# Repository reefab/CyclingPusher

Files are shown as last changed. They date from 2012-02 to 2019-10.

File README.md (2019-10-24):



# CyclingPusher

## Description

This project provides an [Arduino](http://arduino.cc/) sketch that can power an Arduino + Ethernet Shield (or Arduino with built-in ethernet) 
to make a stationary bike computer that can upload Cycling workout sessions results to [Runkeeper](http://runkeeper.com/)'s [Healthgraph API](http://developer.runkeeper.com/healthgraph).
This activity get added to the user's activities feed and could then be posted to Twitter or Facebook automatically by Runkeeper.

It doesn't need to be connected to a computer for that purpose, only a wired ethernet connection is required.

It'll also display the current speed and either the total distance or average speed or elapsed time during normal use via a LCD.

The sensor used is the [reed switch](http://en.wikipedia.org/wiki/Reed_switch) that was already present in my stationary bike connected to the Arduino with a pulldown resistor.

The elapsed time only counts 15 seconds chunks when there was some activity, otherwise it'll pause automatically.

If the pause last more than 2 minutes, it'll upload to Runkeeper the:

 * Starting Time
 * Total Distance
 * Elapsed Time

for the current session. From this, Runkeeper computes the average speed, pace and total calories burned.

## Usage

Plug the ethernet cable and the USB/Power cable in.
The Arduino will beep once it has obtained the current time and is ready for use.

Pedal away and it'll display the current speed while cycling between the total distance. average speed and elapsed time.

Stop pedaling for ~ 15 seconds and the pause screen will come up. 60 seconds, the lcd's backlight will be switched off. 2 minutes and it'll end the session and upload the result or discard the session if the "valid activity" threshold hasn't been reached.

It'll beep every 5km by default.

To start a new session, just use the bike again, it'll start over.

## In action

### Device
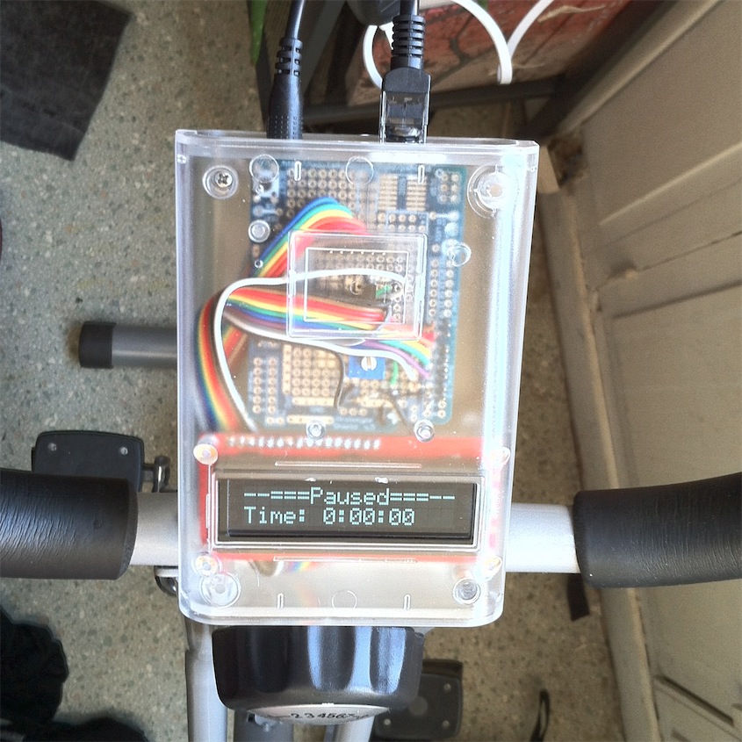
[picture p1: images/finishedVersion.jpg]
Device in clear enclosure

[Prototype during testing](https://github.com/reefab/CyclingPusher/raw/master/images/prototype.jpg)
[Stationary bike's reed switch and magnetic brake](https://github.com/reefab/CyclingPusher/raw/master/images/bike.jpg)
### Runkeeper screenshot
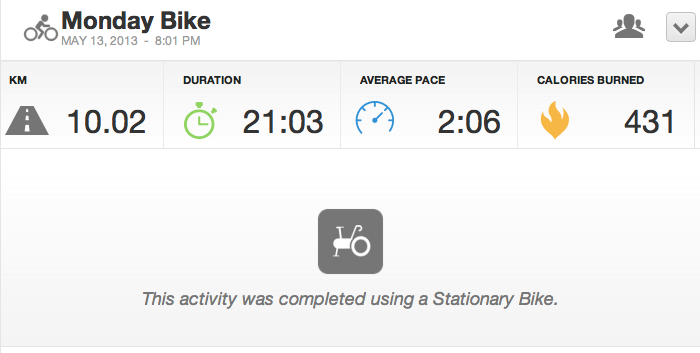
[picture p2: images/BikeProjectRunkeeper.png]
Runkeeper screenshot


## Setup

You'll need:

 * Runkeeper user account
 * create a Runkeeper app to get an access token (See below)
 * Arduino Uno + Ethernet shield or equivalent
 * 16x2 LCD
 * Stationary bike with a reed switch

The reed switch needs to be plugged in Pin2 to use the Arduino's hardware interrupts.

### Schematics

The [Fritzing](http://fritzing.org/) Schema file is available in the `Schematics` directory.
Here is the breadboard view:

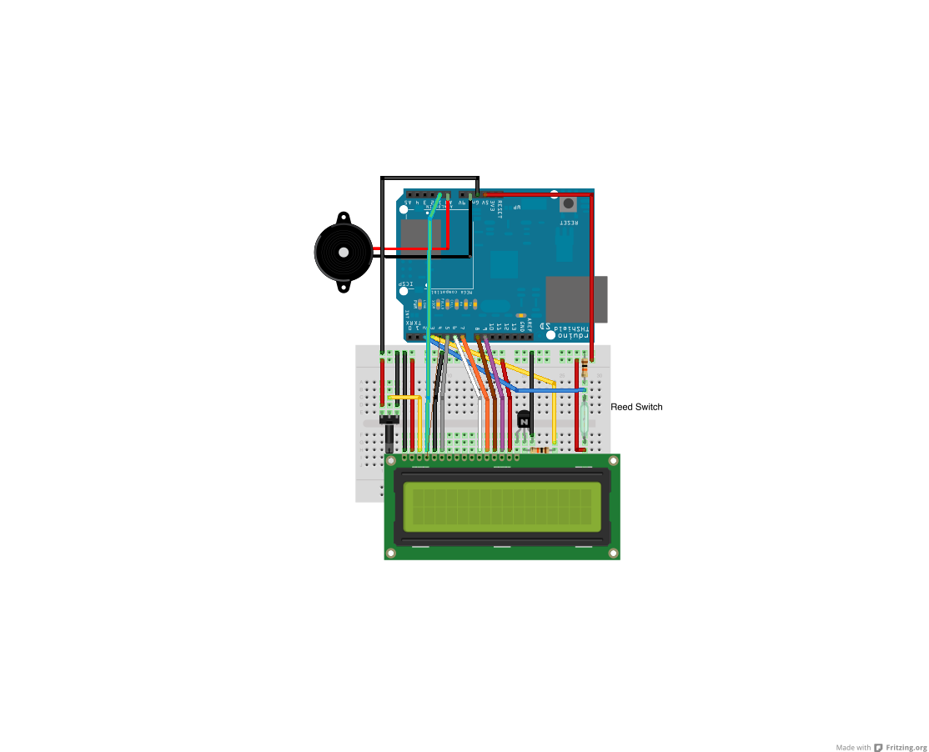
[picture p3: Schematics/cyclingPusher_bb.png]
Breadboard view


### Configuration

You'll need to modify/provide the MAC address and Healthgraph's access token in the config.h (that you'll copy from config.h-dist) file.
You might want to change the number of meters per reed switch activation too.

### How to get the access token

First, once you have your Runkeeper account go to:

http://runkeeper.com/partner/applications/registerForm

Fill in the "Application Name", "Description", "Organization", select "Activity Tracking" and "Estimated Date of Publication".

You'll get a "Client ID" and a "Client Secret".

Open in your browser: https://runkeeper.com/apps/authorize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

Replace XXX with your "Client ID". Authorize your application and it'll try to redirect you to an invalid page but you'll just need the authorization code you'll find in the url bar.

Now, in a shell:

    curl https://runkeeper.com/apps/token \
    -d "grant_type=authorization_code" \
    -d "code=THE_CODE_YOU_JUST_GOT" \
    -d "client_id=XXX" \
    -d "client_secret=XXX" \
    -d "redirect_uri=http%3A%2F%2Flocalhost%3A3001%2Fback"

Please note that the 'redirect_uri' needs to the be exact same one as before.

It'll then give you the access token you can use in your Arduino code.

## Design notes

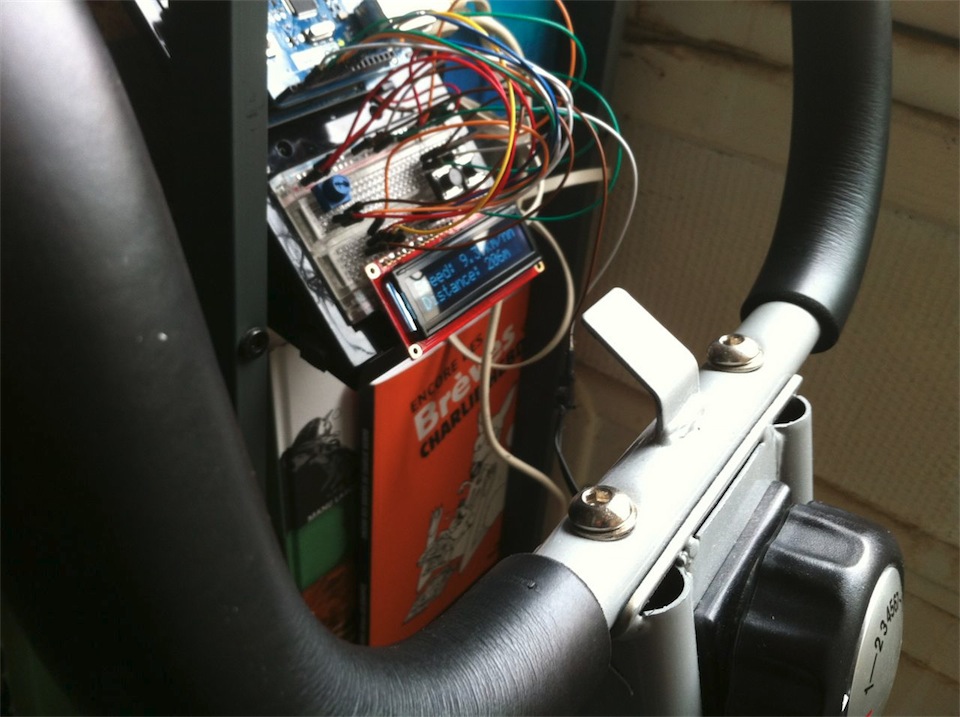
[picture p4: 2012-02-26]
images/prototype.jpg

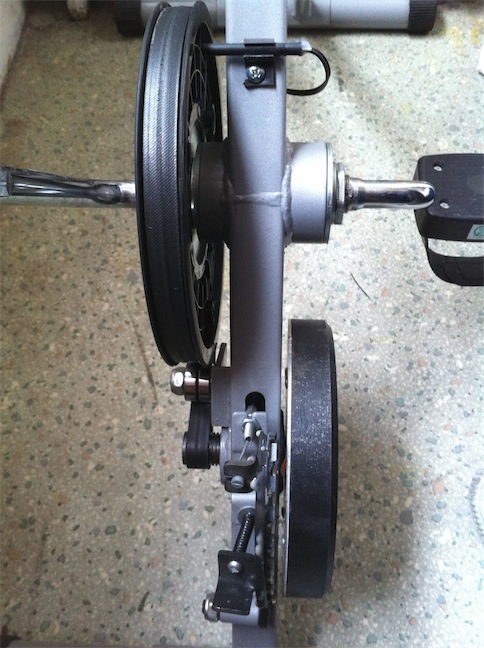
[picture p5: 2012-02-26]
images/bike.jpg

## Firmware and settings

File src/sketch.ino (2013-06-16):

/*
 * Bike
 *
 *  https://github.com/reefab/CyclingPusher
 *
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
 *  Created on: 25.02.2012
 *      Author: reefab@demenzia.net
 */

#include <SPI.h>
#include <Ethernet.h>
#include <EthernetUdp.h>
#include <Dns.h>
#include <Time.h>
#include <IPAddress.h>
#include <EEPROM.h>

EthernetClient client;
DNSClient Dns;

#include "config.h"
#include "ntp.h"
#include "persistent.h"

// This needs to be pin 2 to use interrupt 0
#define reedPin 2
// Number of 'wheel' turns needed to recalculate speed/total distance
#define interval 5
// Minimal number of millisecond between reed switch changes to prevent bounce
#define reedRes 100
// Timeout in seconds, if the reed switch is not activated during this time, pause everything
#define timeOut 15
// Time in seconds before the backlight of the LCD is switched off if there is no activity
#define displaySleep 60
// Minimum distance for a valid activity (in meters)
#define minDistance 500
// least amount of effective time for a valid activity (in secs)
#define minTime 60
// Amount of inactive time before either automatic upload or discarding of current session
#define maxTime 60
// Change the data displayed on the second line of the lcd every X seconds
#define changeSecondLine 3
// Save session data every X seconds
#define saveInterval 120
// Beep shortly every X meters
#define beepInterval 5000

// Global Vars
unsigned int nbRotation = 0;
unsigned int updateCount = 0;
unsigned int totalDistance = 0;
unsigned int lastBeep = 0;
unsigned int beepCount = 0;
unsigned long lastUpdate = 0;
unsigned long currentTime = 0;
unsigned long startTime = 0;
unsigned long enterLoop = 0;
unsigned long exitLoop = 0;
unsigned long time_elasped = 0;
unsigned long effectiveTime = 0;
unsigned long lastSave = 0;
volatile boolean paused = false;
volatile boolean resetRequested = false;
volatile boolean start = false;
volatile unsigned long lastReedPress = 0;
volatile unsigned int rotationCount = 0;
// For display during init and sending via API
String startTimeStr;
float currentSpeed = 0;
boolean done = false;
boolean uploaded = false;

#define lcdblPin 3 // LCD backlight
#include "lcdwrapper.h"
LcdWrapper Lcd(A1, 5, 6, 7, 8, 9, lcdblPin);

#include "display.h"
#include "runkeeper.h"

void setup() {
  delay( 50 );   // allow some time (50 ms) after powerup and sketch start, for the Wiznet W5100 Reset IC to release and come out of reset.
  Serial.begin(9600);
   while (!Serial) {
    ; // wait for serial port to connect. Needed for Leonardo only
  }
  // Using A1 for LCD RS pin
  pinMode(A1, OUTPUT);
  Lcd.begin();

  // Disabling SD slot
  pinMode(4, OUTPUT);
  digitalWrite(4, HIGH);

  pinMode(reedPin, INPUT);

  pinMode(lcdblPin, OUTPUT);
  Lcd.switchBacklight(true);
  Lcd.infoMessage("  Starting up.");

  // start Ethernet
  if(!Ethernet.begin(mac)) {
      Ethernet.begin(mac, ip, gateway, dns_server);
  }
  Serial.print("IP: ");
  Serial.println(Ethernet.localIP());
  delay(1000);
  Dns.begin(Ethernet.dnsServerIP());

  // Upload saved session if present
  if (savePresent()) {
      Lcd.infoMessage("Prev. act. found");
      delay(1000);
      uploaded = uploadResult(getSavedStartTimeStr(), getSavedDistance(), getSavedTime());
      if(uploaded) {
        resetRequested=true;
        eraseProgress();
        Lcd.infoMessage("Saved data uploaded");
        delay(1000);
      }
  }
  Lcd.clear();

  // get time
  /*Lcd.setSecondLine("Getting Time...");*/
  setStartTime();
  delay(1000);
  // Retry if unable to get time from NTP
  while(year() == 1970 or getTimeString().length() <= 10) {
    delay(50000);
    Lcd.errorMessage("Retrying ...");
    setStartTime();
  }
  Serial.print(F("Time: "));
  Serial.println(getTimeString());
  Lcd.clear();

  // Reed switch handling by interrupt
  lastReedPress = millis();
  attachInterrupt(0, turnCounter, RISING);

  // Beeper init
  pinMode(A0, OUTPUT);
  digitalWrite(A0, HIGH);
}

void reset(boolean startNew=false)
{
  rotationCount = 0;
  updateCount = 0;
  totalDistance = 0;
  currentSpeed = 0;
  done = false;
  uploaded = false;
  lastReedPress = millis();
  lastUpdate = 0;
  currentTime = 0;
  startTime = 0;
  time_elasped = 0;
  effectiveTime = 0;
  if (startNew) {
    startTimeStr = getTimeString();
    start = false;
  }
  paused = false;
}

void loop() {
  enterLoop = millis();
  delay(100);
  // Activity finished & api push
  if (done == true && !client.connected() && !uploaded) {
    Lcd.switchBacklight(true);
    Lcd.infoMessage(" Activity ended ");
    saveProgress(startTimeStr, totalDistance, effectiveTime);
    delay(500);
    Lcd.infoMessage(" Activity saved ");
    // Try to upload the saved result
    uploaded = uploadResult(startTimeStr, totalDistance, effectiveTime);
    if(uploaded) {
      resetRequested=true;
      eraseProgress();
    }
    delay(5000);
    Lcd.switchBacklight(false);
  } else {
    // Activity in progres
    // Start a new session if requested
    if (resetRequested) {
      delay(250);
      reset(start);
      if (start) {
        Lcd.infoMessage("Activity started");
      }
      delay(250);
      resetRequested = false;
    }
    // Update turns and distance
    nbRotation = rotationCount - updateCount;
    if (nbRotation >= interval)
    {
      currentTime = millis();
      time_elasped = currentTime - lastUpdate;
      float distance = nbRotation * meterPerTurn;
      currentSpeed = ((float) distance / (float) time_elasped) * 3600;
      totalDistance = rotationCount * meterPerTurn;
      updateCount = rotationCount;
      lastUpdate = currentTime;
    }
    // Update time
    if((millis() - lastReedPress < ((unsigned long) 1000 * timeOut)) && (rotationCount > 0))
    {
      exitLoop = millis();
      effectiveTime = effectiveTime + (exitLoop - enterLoop);
    } else if((millis() - lastReedPress) < ((unsigned long) 1000 * maxTime)) {
      // Automatic activity pause
      paused = true;
      currentSpeed = 0;
      // Display sleep if needed
      if ((( (millis() - lastReedPress) > ((unsigned long) 1000 * displaySleep))))
      {
        Lcd.switchBacklight(false);
      }
    } else {
      // upload session if there is pertinent data, otherwise just reset
      if (isSessionValid()) {
        done = true;
      } else if(rotationCount > 0) {
        Lcd.errorMessage("Discarding data.");
        delay(1000);
        resetRequested = true;
        eraseProgress();
      }
    }
    // Save session data regularly
    if(isSessionValid() && ((millis() - lastSave) > ((unsigned long) 1000 * saveInterval))) {
          saveProgress(startTimeStr, totalDistance, effectiveTime);
          lastSave = millis();
    }
    // Beep if needed
    if(totalDistance >= (beepCount * beepInterval)) {
      beepCount++;
      tone(A0, 2349, 250);
    }

    displayInfo();
  }
}

void turnCounter() {
  if (millis() - lastReedPress > reedRes)
  {
    // Start a new session at first pedal turn
    if (rotationCount == 0) {
      resetRequested = true;
      start = true;
    }
    Lcd.switchBacklight(true);
    if (paused) paused = false;

    rotationCount++;
  }
  lastReedPress = millis();
}

boolean isSessionValid() {
  return ((totalDistance > (unsigned int) minDistance) && (effectiveTime > ((unsigned long) minTime * 1000)));
}

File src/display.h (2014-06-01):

// vim: filetype=arduino

extern float currentSpeed;
extern unsigned int totalDistance;
extern unsigned long effectiveTime;
extern volatile boolean paused;
extern LcdWrapper Lcd;

#include <stdlib.h>

// Change the data displayed on the second line of the lcd every X seconds
#define changeSecondLine 3
#define numberOfSecondLine 3
#define pause_str "--===Paused===--"
#define speed_str "Speed: "
#define distance_str "Distance: "
#define time_str "Time:  "
#define kmh_str "km/h"

unsigned long lastSecondLineChange = 0;
int currentSecondLine = 0;
float avgSpeed = 0;

String floatToString(float float_val)
{
    char number[6];
    if ((int) float_val > 99) {
        return dtostrf(float_val, 5, 1, number);
    } else {
        return dtostrf(float_val, 5, 2, number);
    }
}

String getCurrentSpeedLine()
{
    String line;
    line.reserve(16);
    line += String(speed_str);
    line += floatToString(currentSpeed);
    line += kmh_str;
    return line;
}

String getDistanceLine()
{
    String line;
    line.reserve(16);
    line += String(distance_str);
    if (totalDistance < 1000) {
        line += totalDistance;
        line += "m       ";
    } else {
        line += floatToString((float) totalDistance / 1000U);
        line += "km      ";
    }
    return line;
}

float getAverageSpeed() {
    if (effectiveTime == 0) {
        return 0;
    } else {
        return (float) ((float) totalDistance / effectiveTime) * 3600;
    }
}

String getTimeLine() {
    String time;
    time.reserve(16);
    time += String(time_str + elaspedTime(effectiveTime));
    time += " ";
    return time;
}

String getAvgSpeedLine() {
    String line;
    line.reserve(16);
    line += String("Avg:   ");
    line += floatToString(avgSpeed);
    line += kmh_str;
    return line;
}

void displayInfo() {
    if (paused) {
        Lcd.setFirstLine(pause_str);
    } else {
        Lcd.setFirstLine(getCurrentSpeedLine());
    }
    if ( (millis() - lastSecondLineChange) > ((unsigned long) changeSecondLine * 1000UL)) {
        currentSecondLine = (currentSecondLine + 1) % numberOfSecondLine;
        lastSecondLineChange = millis();
        avgSpeed = getAverageSpeed();
    }
    switch (currentSecondLine) {
        case 0:
            Lcd.setSecondLine(getDistanceLine());
            break;
        case 1:
            Lcd.setSecondLine(getAvgSpeedLine());
            break;
        case 2:
            Lcd.setSecondLine(getTimeLine());
            break;
    }
}

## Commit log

2012-03-05 Big cleanup
    * Separation into multiple files
    * added config file (copy config.h-dist to config.h)
    * pause screen bug fix
    * reordered LCD pins
    * made it easier to support other services instead of just runkeeper
    [display.h]
2012-03-10 Button-less operation
2012-03-25 Nasty, nasty display crash bugs fixed
    [display.h]
2012-03-27 Discovered the "volatile" keyword and why I should have used it before for my interrupt handling
2012-03-27 Updated documentation + picture of the finished device
2012-03-27 Added schematics
    [cyclingPusher.fzz]
2012-03-29 Schematic modification
    [cyclingPusher.fzz]
2012-03-29 Schemas updates
    [cyclingPusher.fzz]
2012-04-08 Crash bug hopefully fixed
    [display.h]
2012-04-18 Working "offline" support using EEPROM to save session data
    The session activity data will be saved every minute to the Arduino's
    EEPROM and before uploading.
    If uploading fail or the Arduino lose power during a workout session,
    it'll try to upload the saved data during next boot.
2012-11-04 Fixed for Arduino 1.0.1:
    * had to remove DCHP support as it didn't fit in flash anymore
    * now beeps once every 5km by default
2012-11-04 Updated documentation
    [cyclingPusher.fzz]
2013-01-09 Ripped out the HTTPClient library and rewrote the HTTP POST Request code from scratch.
    Should be more reliable, I think that library was the culprit in failing uploads. Also was too big for the amount of feature used (one in my case).
2013-01-11 Fixed bug in the Time library: The 3 letter short name for Thursday should be "Thu" and not "Thr"…
    All activities during this weekday was rejected by Healthgraph API because of that.
2013-01-11 Found out that Healthgraph's API now supports specifying the equipment type. So now activities have the correct "Stationary Bike" equipment tag attached to them.
2013-01-31 * Small cleanup * code checked with cppcheck but no errors found.
    [display.h, sketch.ino]
2013-03-03 Putting all LCD related features in a wrapper lib around the Arduino's basic LCD library
2013-05-13 Using String.reserve() to prevent memory fragmentation
    [display.h, sketch.ino]
2013-06-12 Changed the RS pin from 4 to A1 as the SD card slot that uses pin 4 might have been interfering all along...
    [sketch.ino]
2013-06-12 Updated schematics and Runkeeper screenshot to reflect their redesign
    [cyclingPusher.fzz]
2013-06-14 Updated sample configuration file
2013-06-16 Fixed Requests and added a small test server to troubleshoot the client
    [sketch.ino]
2014-06-01 Fixed variable scope issues in libraries.
    [display.h]

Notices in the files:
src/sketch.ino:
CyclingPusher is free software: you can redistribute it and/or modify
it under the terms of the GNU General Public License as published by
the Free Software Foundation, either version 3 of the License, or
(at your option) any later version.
